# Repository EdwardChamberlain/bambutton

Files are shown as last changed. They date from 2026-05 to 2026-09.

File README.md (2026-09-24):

# Bambutton
A physical plate-clear button for Bambuddy

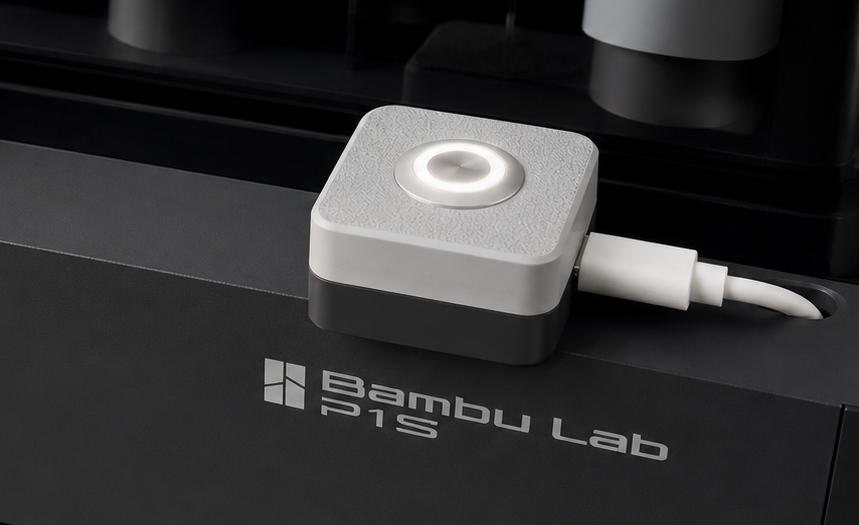
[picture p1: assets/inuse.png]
Bambutton in use on a P1S


Bambutton turns a small ESP32-C3 board into a dedicated wireless control for your printer. The LED ring flashes to show when a plate needs clearing, and one button press marks the plate as clear in Bambuddy so the next queued job can be despatched automatically.

It gives each printer a simple shop-floor control that is easy to see, quick to press, and smoother than opening the Bambuddy interface every time.

## Contents

- [Flashing Tool](#flashing-tool)
- [Manual Flashing](#manual-flashing)
  - [Configure the board](#configure-the-board)
  - [Run without auto-start](#run-without-auto-start)
- [Web GUI](#web-gui)
- [Release Packaging](#release-packaging)
- [Hardware](#hardware)
  - [Purchased Parts](#purchased-parts)
  - [Printed Parts](#printed-parts)
  - [Wiring Notes](#wiring-notes)

## Flashing Tool

For the simplest setup, download the [latest release](https://github.com/EdwardChamberlain/Bambutton/releases/latest)
and run the Bambutton setup assistant. It detects the connected ESP32-C3 automatically, flashes the bundled
MicroPython firmware and application files, and offers two setup modes:

- **Web GUI setup** flashes the board without a saved configuration. Configure
  it from the board's web page after flashing.
- **Config-based setup** flashes an existing `config.json`. The assistant can
  save an example configuration for you to edit first. Enable **Randomise
  hostname for each board** to append a fresh four-character suffix to the
  configured hostname for each flash, which avoids hostname conflicts when
  provisioning multiple boards from the same file.

The release tool does not require Python, `mpremote`, or `esptool`. Connect the
board with a data-capable USB cable before starting the flash.

To run the assistant from source during development:

```bash
python -m pip install -r requirements.txt
python src/bambutton_config_gui.py
```

## Manual Flashing

Use this route for development or when you prefer the command line. You need
Python, a data-capable USB cable, and an ESP32-C3 connected over USB.

Create and activate a virtual environment, then install the flashing tools:

```bash
python -m venv .venv
```

On macOS or Linux, activate it with:

```bash
source .venv/bin/activate
```

On Windows PowerShell, activate it with:

```powershell
.venv\Scripts\Activate.ps1
```

Then install the flashing tools:

```bash
python -m pip install --upgrade pip
python -m pip install -r requirements.txt
```

### Configure the board

Edit `micro/config.json` with the Wi-Fi network, Bambuddy API URL and key, the
printer ID, and any hardware pin changes. The default wiring is GPIO 3 for the
LED and GPIO 4 for the button. `micro/config_example.json` is a clean template
if you need one.

Erase the board, flash the bundled ESP32-C3 MicroPython firmware, and copy the
application files:

```bash
python -m esptool --chip esp32c3 --port /dev/tty.usbmodemXXXX erase_flash
python -m esptool --chip esp32c3 --port /dev/tty.usbmodemXXXX write_flash -z 0x0 firmware/ESP32_GENERIC_C3-20260406-v1.28.0.bin
python scripts/push_micro.py --clean
```

Replace `/dev/tty.usbmodemXXXX` with the board's serial port. `mpremote` can
usually find the port automatically; if it cannot, pass it to the copy script:

```bash
python scripts/push_micro.py --clean --device /dev/tty.usbmodemXXXX
```

The copy script resets the board when it finishes. To update only the
configuration later:

```bash
mpremote cp micro/config.json :
mpremote reset
```

The repository includes a firmware image for the ESP32-C3 Generic board. Check
the [latest MicroPython ESP32-C3 release](https://micropython.org/download/ESP32_GENERIC_C3/)
if you want to use a newer compatible image.

### Run without auto-start

To copy support files without installing `main.py` as the board's auto-starting
application, then run it from the host:

```bash
python scripts/push_micro.py --clean --no-main
python scripts/run_main.py
```

Pass `--device /dev/tty.usbmodemXXXX` to either script when automatic port
detection is unavailable.

## Web GUI

After flashing with Web GUI setup, the board starts a setup access point when it
cannot connect to configured Wi-Fi. Connect to the board's wifi (for
example, `bambutton-ABCD`) with and use username `admin`, password `bambutton`, then open
`http://192.168.4.1/`. Enter the Wi-Fi, Bambuddy API,
printer, and pin settings and choose **Save and restart**.

Once connected to Wi-Fi, open the board's hostname or assigned IP address. The
page can load printers from Bambuddy and update the board without USB. The debug page reports
runtime state without exposing secrets.

### Application updates

The web page's application update section can check the latest official release
or stage a local `bambutton-ota.json` bundle. Updates are written to the
inactive application slot, verified using file sizes and SHA-256 hashes, and
activated by a crash-safe append-only slot pointer. The previous slot is retained until
the new application confirms a healthy boot, so interrupted transfers and failed
restarts roll back automatically. Wi-Fi, API, printer, and web settings remain
in `config.json` and are never part of an application update.

The first OTA-capable installation must be flashed over USB so the stable
bootloader and migration code are installed. The USB helper stages the complete
runtime before installing the boot hook, preserves an existing legacy
`main.py`, and migrates the application into slot A on the next boot. Full
MicroPython firmware updates still require USB flashing.

## Release Packaging

Package versions are derived from Git tags via `hatch-vcs`. A tag beginning with
`v` starts the GitHub release workflow:

```bash
git tag v0.1.0
git push origin v0.1.0
```

The workflow attaches Windows and macOS setup-tool archives, the verified
`bambutton-ota.json` application bundle, plus a Python wheel and source
distribution. To build the Python distribution locally:

```bash
python -m pip install ".[dev]"
python -m build
```

Build an application bundle locally with:

```bash
python scripts/build_ota_bundle.py --version 0.2.0 --output dist/bambutton-ota.json
```

## Hardware

### Purchased Parts

- [ESP32-C3 Super Mini](https://www.aliexpress.com/item/1005008805263277.html?spm=a2g0o.order_list.order_list_main.5.61041802T9J6qU)
- [LED Button](https://www.aliexpress.com/item/1005004920346156.html?) - select the **16 mm, 3-6V momentary** option. The case and assembly instructions are designed for this button size.

### Printed Parts

The top and bottom housing files are available on [makerworld](https://makerworld.com/en/models/2747607-bambutton-on-machine-bambuddy-plate-tracking).

These parts are designed to fit the hardware listed above.

You can print the housing in any colour or material you like. I found it useful to apply a small piece of double-sided tape to the ESP32-C3 board to hold it in place during assembly.

The small alignment holes are designed to accept short pieces of 1.75 mm filament (6 mm should do it!), which can be used as simple dowel pins to align the top and bottom halves.

The housing can be secured with 4 × M3×12 cap head bolts. These may not be required if the filament dowels are a tight enough fit.

I have also included a printed tool for doing up the M16 nut on the button as otherwise it is a bit difficult!

### Wiring Notes

The default configuration matches this final wiring:

```text
GPIO3 -> LED -> GND
GPIO4 -> button -> 3V3
```

Use GPIO numbers, not physical pin positions.

#### Button wiring:
- Connect one side of the momentary switch to GPIO 4 or your configured pin.
- Connect the other side of the switch to 3V3.
- The firmware enables the ESP32-C3 internal pull-down, so the button reads low when idle and high when pressed.
- The interrupt is configured for the rising edge, so it triggers on button press.

#### LED wiring:
- The LED output defaults to GPIO 3.
- Wire GPIO 3 to the LED anode through a suitable current-limiting resistor, then wire the LED cathode to GND.
- If wiring the LED inside the external button, connect it only according to the button's voltage/current requirements.
- Do not feed 5V into an ESP32-C3 GPIO. ESP32-C3 GPIO is 3.3V logic.
- If the button LED needs more current than a GPIO can safely provide, drive it through a transistor/MOSFET instead of directly from the GPIO.

> Note: When Wi-Fi is unavailable, the LED blinks at twice the plate-clear alert rate to show the connection failure. When connected, its standby state is tied to the printer's chamber light state, so turning off the printer light turns off the standby light on the button.

#### Power and USB:

- Use a data-capable USB cable for programming. Charge-only USB cables will power the board but will not appear to `mpremote`.
- Power the ESP32-C3 from USB during setup and flashing.
- Disconnect power before changing wiring.
- Once configured a "power only" cable will be ok as no data is transferred.
- You can power this from the P1S internal USB port.

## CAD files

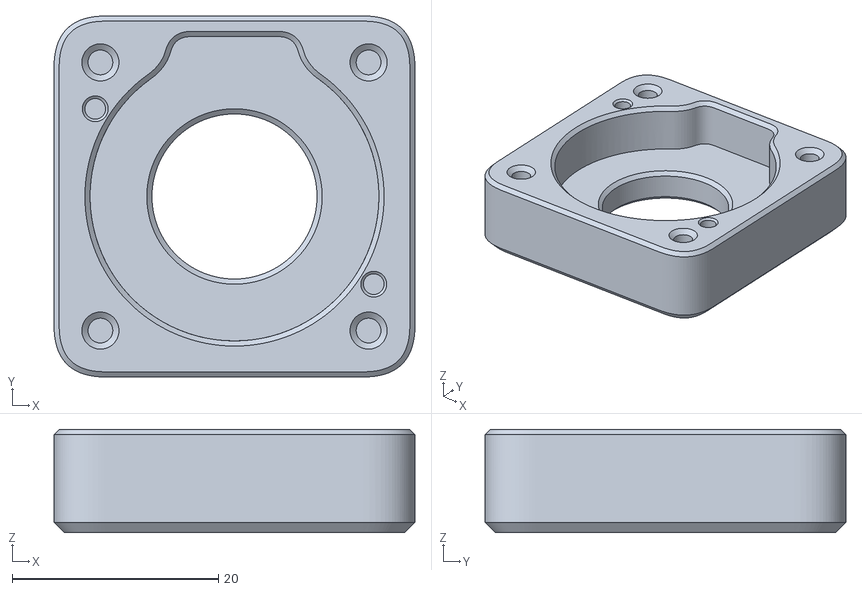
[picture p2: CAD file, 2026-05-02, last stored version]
printed_parts/top.stl
35.0 x 35.0 x 10.00

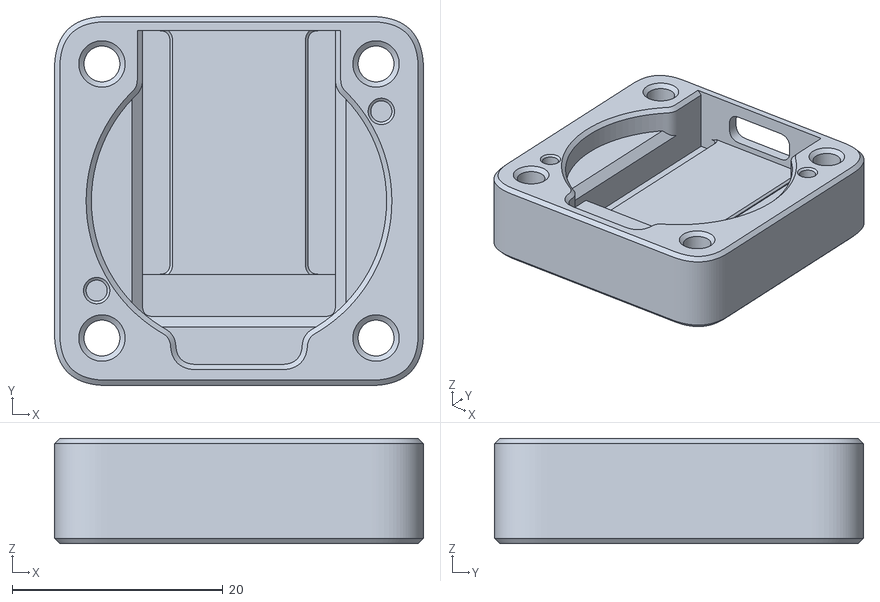
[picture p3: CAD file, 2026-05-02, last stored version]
printed_parts/base.stl
35.0 x 35.0 x 10.00

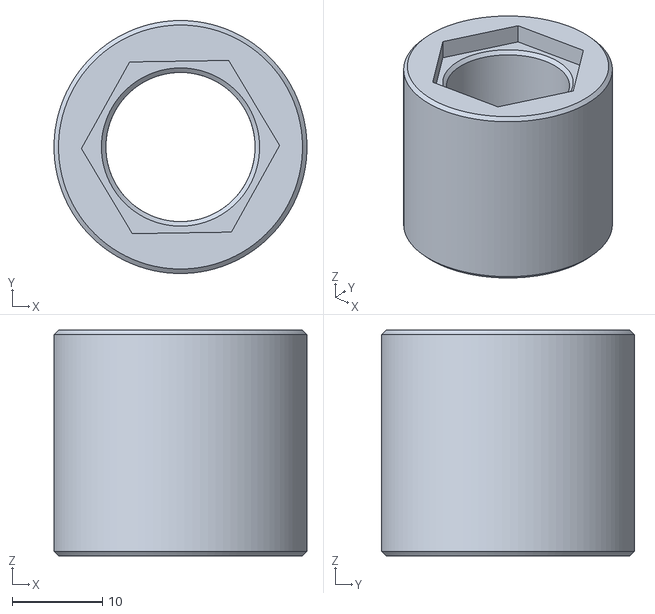
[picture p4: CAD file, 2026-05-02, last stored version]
printed_parts/Nut Tool.stl
28.0 x 28.0 x 25.0

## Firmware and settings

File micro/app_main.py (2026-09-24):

import machine
import time
import bambuddy_api
import config_loader
import gpio_button
import led_flasher
import ota_manager
import wifi
import periodic_timer
import web_config


config = config_loader.load_config()

# -- Runtime Flags ---
PRINTER_AWAITING_PLATE_CLEAR = False
PENDING_BUTTON_PRESS = False
BUTTON_PRESS_NEEDS_RECONCILIATION = False
BUTTON_PRESS_RETRY_AT_MS = None
CHAMBER_LIGHT_IS_ON = True
PRINTER_STATUS_UPDATE_REQUIRED = True
network = None
BUTTON_PRESS_RETRY_DELAY_MS = 5_000
AP_RETRY_INTERVAL_MS = wifi.AP_RETRY_INTERVAL_SECONDS * 1000


def should_flash_connection_failure():
    # Keep the connection failure indication active during boot, before the
    # Wi-Fi helper has been created, and whenever the interface drops later.
    return network is None or not network.is_connected()


def should_flash_plate_clear():
    return PRINTER_AWAITING_PLATE_CLEAR or PENDING_BUTTON_PRESS


# Feed this from the main loop and during each bounded Wi-Fi attempt/backoff.
# If a request or the networking stack blocks, the board will reboot.
watchdog = machine.WDT(timeout=60_000)

# -- Initialize LED flasher ---
flasher = led_flasher.LedFlasher(
    pin_number=config["led"]["pin"],
    should_flash=should_flash_plate_clear,
    interval_ms=config["led"]["flash_interval_ms"],
    inactive_value=lambda: CHAMBER_LIGHT_IS_ON,
    fast_should_flash=should_flash_connection_failure,
)
flasher.start()


# -- Button handler ---
def IRQ_button_press(pin):
    global PENDING_BUTTON_PRESS
    global PRINTER_AWAITING_PLATE_CLEAR
    global BUTTON_PRESS_NEEDS_RECONCILIATION, BUTTON_PRESS_RETRY_AT_MS

    # Keep the interrupt allocation-free and retain one intent until confirmed.
    if PRINTER_AWAITING_PLATE_CLEAR:
        PRINTER_AWAITING_PLATE_CLEAR = False
        PENDING_BUTTON_PRESS = True
        BUTTON_PRESS_NEEDS_RECONCILIATION = False
        BUTTON_PRESS_RETRY_AT_MS = None


button = gpio_button.GPIOButton(
    pin_number=config["button"]["pin"],
    on_press=IRQ_button_press,
    debounce_ms=config["button"]["debounce_ms"],
    pull=config["button"]["pull"],
    trigger=config["button"]["trigger"],
)
button.start()


# -- Connect to Wi-Fi --
network = wifi.WiFi(
    ssid=config["wifi"]["ssid"],
    password=config["wifi"]["password"],
    hostname=config["wifi"].get("hostname", wifi.DEFAULT_HOSTNAME),
    ap_password=config["wifi"].get("ap_password", wifi.DEFAULT_AP_PASSWORD),
    status_led=None,
    timeout_seconds=config["wifi"]["timeout_seconds"],
)
printer_api_ready = config_loader.is_runtime_config_ready(config)
if printer_api_ready:
    network.connect_with_fallback(watchdog_feed=watchdog.feed)
else:
    # Keep the setup UI reachable until a complete, explicit printer
    # configuration has been saved. In particular, do not poll or clear the
    # baked-in/default printer ID while settings are incomplete.
    network.start_access_point()
if network.is_ap_mode():
    print("Wi-Fi unavailable; connect to the setup access point to update settings")
    flasher.on()
last_ap_retry_ms = time.ticks_ms()

# -- Initialize API client --
api = bambuddy_api.BambuddyAPI(
    config["api"]["key"],
    config["api"]["base_url"],
    config["api"]["request_timeout_seconds"],
)


# --- Setup Polling Loop ---
def IRQ_printer_update_tick():
    global PRINTER_STATUS_UPDATE_REQUIRED
    PRINTER_STATUS_UPDATE_REQUIRED = True


poll_timer = periodic_timer.PeriodicTimer(
    period_ms=config["printer"]["poll_interval_seconds"] * 1000,
    callback=IRQ_printer_update_tick,
)
poll_timer.start()


# --- Main loop handlers ---
def with_network_connection(request):
    if network.is_ap_mode():
        raise RuntimeError("Wi-Fi setup access point is active")

    network.ensure_connected(watchdog_feed=watchdog.feed, fallback_to_ap=True)
    if network.is_ap_mode():
        raise RuntimeError("Wi-Fi setup access point is active")
    return request()


def handle_pending_button_press():
    global PENDING_BUTTON_PRESS, BUTTON_PRESS_NEEDS_RECONCILIATION
    global BUTTON_PRESS_RETRY_AT_MS
    global PRINTER_AWAITING_PLATE_CLEAR, PRINTER_STATUS_UPDATE_REQUIRED

    if not PENDING_BUTTON_PRESS:
        return
    if (
        BUTTON_PRESS_RETRY_AT_MS is not None
        and time.ticks_diff(BUTTON_PRESS_RETRY_AT_MS, time.ticks_ms()) > 0
    ):
        return

    if not printer_api_ready:
        PENDING_BUTTON_PRESS = False
        return

    try:
        if BUTTON_PRESS_NEEDS_RECONCILIATION:
            response = with_network_connection(
                lambda: api.get_printer_status(config["printer"]["id"])
            )
            apply_printer_status(response)
            BUTTON_PRESS_NEEDS_RECONCILIATION = False
            if not PENDING_BUTTON_PRESS:
                return

        outcome = with_network_connection(
            lambda: api.clear_plate_with_reconciliation(config["printer"]["id"])
        )
        if outcome["status"] is not None:
            apply_printer_status(outcome["status"])
        if outcome["resolved"]:
            PENDING_BUTTON_PRESS = False
            PRINTER_AWAITING_PLATE_CLEAR = False
            BUTTON_PRESS_NEEDS_RECONCILIATION = False
            BUTTON_PRESS_RETRY_AT_MS = None
            PRINTER_STATUS_UPDATE_REQUIRED = outcome["status"] is None
            return

        print("Plate-clear request was not applied:", outcome["request_error"])
        BUTTON_PRESS_RETRY_AT_MS = time.ticks_add(
            time.ticks_ms(), BUTTON_PRESS_RETRY_DELAY_MS
        )

    except Exception as exc:
        print("Failed to send plate clear request:", exc)
        BUTTON_PRESS_NEEDS_RECONCILIATION = True
        BUTTON_PRESS_RETRY_AT_MS = time.ticks_add(
            time.ticks_ms(), BUTTON_PRESS_RETRY_DELAY_MS
        )
        PRINTER_STATUS_UPDATE_REQUIRED = True


def apply_printer_status(response):
    global PRINTER_AWAITING_PLATE_CLEAR, CHAMBER_LIGHT_IS_ON
    global PENDING_BUTTON_PRESS, BUTTON_PRESS_NEEDS_RECONCILIATION

    PRINTER_AWAITING_PLATE_CLEAR = response["awaiting_plate_clear"]
    CHAMBER_LIGHT_IS_ON = response["chamber_light"]
    if PENDING_BUTTON_PRESS:
        if PRINTER_AWAITING_PLATE_CLEAR:
            BUTTON_PRESS_NEEDS_RECONCILIATION = False
        else:
            PENDING_BUTTON_PRESS = False
            BUTTON_PRESS_NEEDS_RECONCILIATION = False


def handle_printer_status_update():
    global PRINTER_STATUS_UPDATE_REQUIRED

    if not printer_api_ready:
        PRINTER_STATUS_UPDATE_REQUIRED = False
        return

    try:
        response = with_network_connection(
            lambda: api.get_printer_status(config["printer"]["id"])
        )
        apply_printer_status(response)

        print(
            "Printer awaiting plate clear:",
            PRINTER_AWAITING_PLATE_CLEAR,
            "Chamber light is on:",
            CHAMBER_LIGHT_IS_ON,
        )

    except Exception as exc:
        print("Failed to fetch printer status:", exc)

    PRINTER_STATUS_UPDATE_REQUIRED = False


def debug_status():
    try:
        network_config = network.ifconfig()
    except Exception as exc:
        network_config = ("unavailable: {}".format(exc),)

    status = {
        "Network mode": network.mode(),
        "Wi-Fi connected": network.is_connected(),
        "IP address": network_config[0] if network_config else "unavailable",
        "Awaiting plate clear": PRINTER_AWAITING_PLATE_CLEAR,
        "Button press pending": PENDING_BUTTON_PRESS,
        "Chamber light on": CHAMBER_LIGHT_IS_ON,
        "Status update pending": PRINTER_STATUS_UPDATE_REQUIRED,
    }
    status.update({
        "Application version": ota_manager.OTAUpdateManager().status().get(
            "current_version", "legacy"
        ),
    })
    return status


try:
    update_manager = ota_manager.OTAUpdateManager(reset=machine.reset)
    web_server = web_config.WebConfigServer(
        config=config,
        api=api,
        status_provider=debug_status,
        update_manager=update_manager,
    )
    print("Web configuration available at http://{}/".format(network.ifconfig()[0]))
except Exception as exc:
    update_manager = ota_manager.OTAUpdateManager(reset=machine.reset)
    web_server = None
    print("Web configuration server unavailable:", exc)

# -- Main loop --
boot_confirmed = False
while True:
    watchdog.feed()

    restart_requested = web_server is not None and web_server.poll()

    if (
        network.is_ap_mode()
        and time.ticks_diff(time.ticks_ms(), last_ap_retry_ms)
        >= AP_RETRY_INTERVAL_MS
    ):
        network.retry_station_from_access_point(watchdog_feed=watchdog.feed)
        last_ap_retry_ms = time.ticks_ms()

    # Push button press to API if pending
    if not restart_requested and not network.is_ap_mode() and PENDING_BUTTON_PRESS:
        handle_pending_button_press()

    # Check printer status
    if (
        not restart_requested
        and not network.is_ap_mode()
        and PRINTER_STATUS_UPDATE_REQUIRED
    ):
        handle_printer_status_update()

    # Confirm only after services have initialized and the first complete main
    # loop pass has run. An early runtime exception or watchdog reset remains
    # eligible for bootloader rollback.
    if web_server is not None and not boot_confirmed:
        update_manager.confirm_boot()
        boot_confirmed = True

    if restart_requested:
        print("Restart requested")
        time.sleep_ms(100)
        machine.reset()

    time.sleep_ms(25)

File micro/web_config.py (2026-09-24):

import socket

try:
    import ujson as json
except ImportError:
    import json

try:
    import ubinascii as _base64
except ImportError:
    import base64 as _base64

try:
    import ota_manager
    import config_loader
except ImportError:
    from micro import ota_manager, config_loader

save_config = config_loader.save_config


CONFIG_PATH = "config.json"
DEFAULT_HOSTNAME = "bambutton"
DEFAULT_WEB_PASSWORD = "bambutton"
WEB_AUTH_USERNAME = "admin"
MAX_REQUEST_BYTES = 128 * 1024


class WebConfigServer:
    """Small polled configuration server for the MicroPython board.

    The server is deliberately polled from the main loop instead of running a
    second thread. That keeps configuration writes and application state in one
    execution context while the server is available on station or AP Wi-Fi.
    """

    def __init__(
        self,
        config,
        api,
        status_provider=None,
        config_path=CONFIG_PATH,
        host="0.0.0.0",
        port=80,
        socket_module=socket,
        update_manager=None,
    ):
        self.config = config
        self.api = api
        self.status_provider = status_provider or (lambda: {})
        self.config_path = config_path
        self.socket_module = socket_module
        self.update_manager = update_manager or ota_manager.OTAUpdateManager()
        self.restart_requested = False

        self.listener = socket_module.socket()
        try:
            self.listener.setsockopt(
                socket_module.SOL_SOCKET,
                socket_module.SO_REUSEADDR,
                1,
            )
        except (AttributeError, OSError):
            pass

        self.listener.bind((host, port))
        self.listener.listen(1)
        self.listener.settimeout(0)

    def close(self):
        if self.listener is not None:
            self.listener.close()
            self.listener = None

    def poll(self):
        """Handle at most one browser request without blocking the main loop."""
        if self.listener is None:
            return False

        client = None
        try:
            client, _address = self.listener.accept()
            client.settimeout(0.25)
            method, path, body, headers = _read_request(client)
            status, content_type, response_body = self.handle_request(
                method,
                path,
                body,
                headers,
            )
            response_headers = {}
            if status == 401:
                response_headers["WWW-Authenticate"] = 'Basic realm="Bambutton"'
            _send_response(client, status, content_type, response_body, response_headers)
        except OSError:
            # A non-blocking listener reports no pending connection as OSError.
            # Request-level socket errors are also safe to ignore: the next
            # browser request can retry without affecting the button loop.
            pass
        except Exception as exc:
            if client is not None:
                try:
                    _send_response(
                        client,
                        500,
                        "text/html; charset=utf-8",
                        _error_page("Web configuration error", str(exc)),
                    )
                except OSError:
                    pass
        finally:
            if client is not None:
                client.close()

        restart_requested = self.restart_requested
        self.restart_requested = False
        return restart_requested

    def handle_request(self, method, path, body="", headers=None):
        update_manager = self._get_update_manager()
        if not self._is_authorized(headers or {}):
            return 401, "text/html; charset=utf-8", _error_page(
                "Authentication required",
                "Enter the configured web password to access this board.",
            )

        route = path.split("?", 1)[0]

        if method == "GET" and route in ("/", "/index.html"):
            message = ""
            if "saved=1" in path:
                message = "Settings saved. The board will restart to apply them."
            return 200, "text/html; charset=utf-8", render_config_page(
                self.config,
                message,
                update_manager.status(),
            )

        if method == "GET" and route == "/update":
            return 200, "text/html; charset=utf-8", render_update_page(
                update_manager.status()
            )

        if method == "GET" and route == "/api/update/status":
            return 200, "application/json", _json_dumps(
                update_manager.status()
            )
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

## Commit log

2026-04-25 fix recursive launch bug
    [gui.py]
2026-04-25 Fix mac app launch recursion
    [gui.py]
2026-04-26 Fix release tag filter
2026-05-02 Update button and LED configurations: change GPIO pins, add pull and trigger settings
2026-05-02 Add base and top STL files for printed parts
    [base.stl, top.stl]
2026-05-02 Add printed parts section to README with housing details and assembly tips
2026-05-02 Add printed tool for M16 nut and update README with usage details
    [Nut Tool.stl]
2026-05-02 Add local board credentials to .gitignore
2026-05-02 Remove obsolete STL files for Nut Tool, base, and top components - move to makerworld
    [Nut Tool.stl, base.stl, top.stl]
2026-05-02 Update README to link printed parts housing files on makerworld
2026-05-02 Clarify GPIO wiring instructions in README by removing redundant text and unnecessary code block
2026-05-02 Add periodic timer functionality and refactor button handling in main loop
2026-05-02 Refactor LedFlasher to use PeriodicTimer and simplify timer management
2026-05-02 Remove inactive_value from LED configuration in multiple files
2026-05-02 Invert inactive_value logic in LedFlasher to ensure correct LED state handling
    [led_flasher.py]
2026-05-02 Fetch printer status in a single API call and update related flags
2026-05-02 Fix LED state handling by using inactive_value directly in LedFlasher
    [led_flasher.py]
2026-07-03 Update README with LED state note
    Added note about LED state relation to printer's chamber light.
2026-07-03 Set Wi-Fi transmit power configuration during connection
2026-07-03 add periodic timer to build
2026-07-19 fix: implement network recovery watchdog and ensure Wi-Fi reconnection
    [wifi.py]
2026-07-19 fix: add request timeout configuration for API requests
    [api.py, config_loader.py, gpio_button.py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]
2026-07-19 fix: comment out unused WLAN configuration for txpower
    [wifi.py]
2026-09-05 fix: disable Wi-Fi power saving for button responsiveness
    [test_wifi.py, wifi.py]
2026-09-09 docs: specify 16 mm button size
2026-09-10 fix: complete web configuration flows
    [test_packaging.py, test_web_config.py, web_config.py]
2026-09-10 feat: blink LED when Wi-Fi is unavailable
2026-09-10 feat: speed up connection failure blinking
    [led_flasher.py, test_led_flasher.py]
2026-09-10 fix: retry Wi-Fi connection indefinitely
    [test_wifi.py, wifi.py]
2026-09-10 fix: retry Wi-Fi connection OSErrors
    [test_wifi.py, wifi.py]
2026-09-10 fix: require web password in setup AP
    [web_config.py]
2026-09-10 feat: auto-detect board serial port
2026-09-11 fix: match config input height to buttons
    [gui.py]
2026-09-11 style: clarify disabled button state
2026-09-11 fix: unify browse button hover styling
    [gui.py]
2026-09-11 test: cover mobile button styling
2026-09-15 fix: constrain hostname randomisation to config flashes
    [gui.py, test_gui.py]
2026-09-23 fix: recover from candidate import failures
    [ota_manager.py, test_ota_manager.py]
2026-09-23 fix: make OTA state and bootstrap recovery safe
    [boot.py, gui.py, ota_manager.py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]
2026-09-23 fix: recover interrupted bootstrap installation
    [gui.py, ota_manager.py, test_ota_manager.py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]
2026-09-23 fix: preserve bootstrap recovery marker
    [gui.py, test_push_micro.py]
2026-09-23 fix: rollback failed first-install migration
    [ota_manager.py, test_ota_manager.py]
2026-09-24 fix: close atomic OTA readiness blockers
    [app_main.py, boot.py, gui.py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]
2026-09-24 fix: show OTA slot state and update progress
    [test_push_micro.py, test_web_config.py, web_config.py]
2026-09-24 fix: recover interrupted settings saves (#38)
    [config_loader.py, test_config_loader.py, test_web_config.py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]
2026-09-24 fix: retain plate-clear presses after request failures (#39)
    [app_main.py, bambuddy_api.py, test_app_main.py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]
2026-09-24 fix: validate bounded OTA bundles before release (#40)
    [ota_manager.py, test_ota_manager.py, test_validate_ota_bundle.py]
2026-09-24 ci: install desktop smoke wheel cross-platform
2026-09-24 Fix incomplete config recovery safety
    [app_main.py, config_loader.py, test_config_loader.py]
2026-09-24 test: keep plate-clear branch compatible with startup gate
2026-09-24 fix: use available filesystem blocks for OTA staging
    [ota_manager.py, test_ota_manager.py]
2026-10-29 Fix boot memory pressure after OTA slot verification
